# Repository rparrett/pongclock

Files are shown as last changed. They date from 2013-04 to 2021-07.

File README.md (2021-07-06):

Pongclock
=========

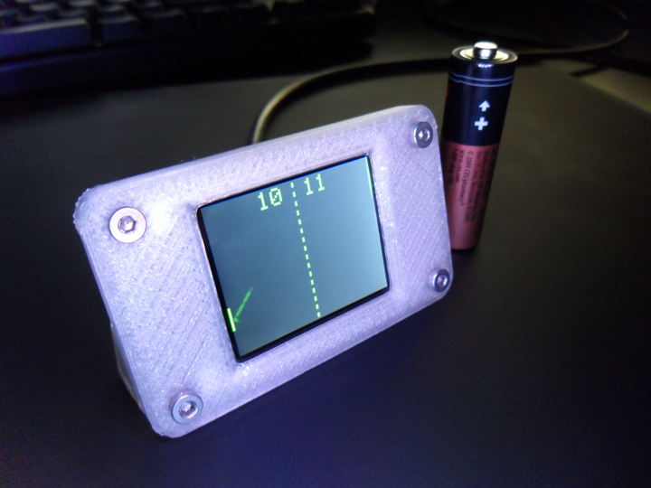
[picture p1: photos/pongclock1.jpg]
Pongclock


* it's a clock
* arduino compatible
* 1.8" tft display
* powered by usb
* 4 buttons

Dependencies
============
* Arduino 1.6.9
* https://github.com/adafruit/Adafruit-ST7735-Library @ 8ad728d736d32820dab30c9653d1a61fb6a33ab8
* https://github.com/adafruit/Adafruit-GFX-Library @ 334e815bc1dd3f93f93c45b77b4f33bdc9bfc8c5
* https://github.com/adafruit/RTClib @ f0385ab04897f27e7f625eb7a8d2c7671051df96
* https://github.com/thomasfredericks/Bounce2 @ 8b60f9f057db7dbf7dfd395cfcc2ecaadb4ccb9a

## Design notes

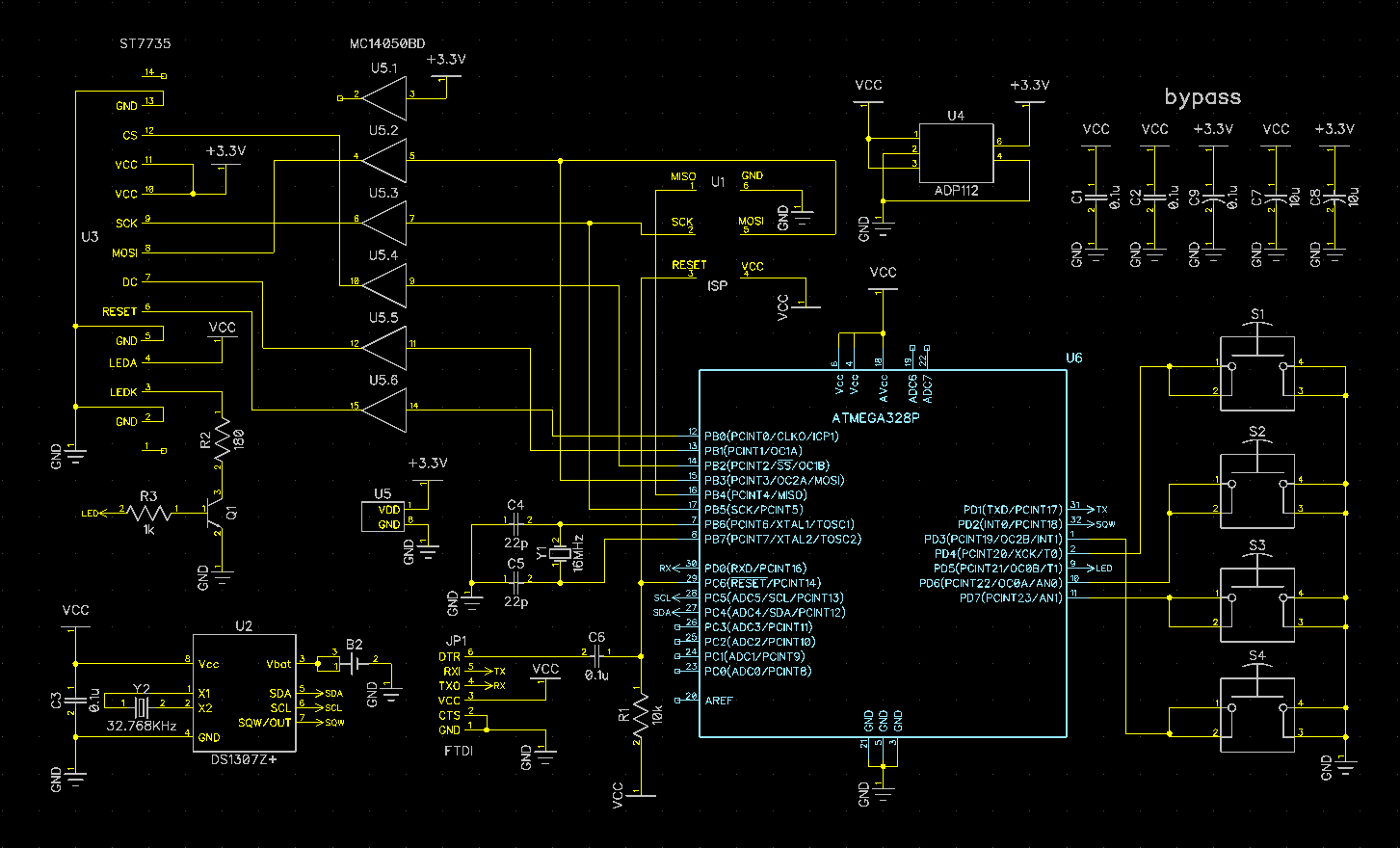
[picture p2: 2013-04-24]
schematic.PNG

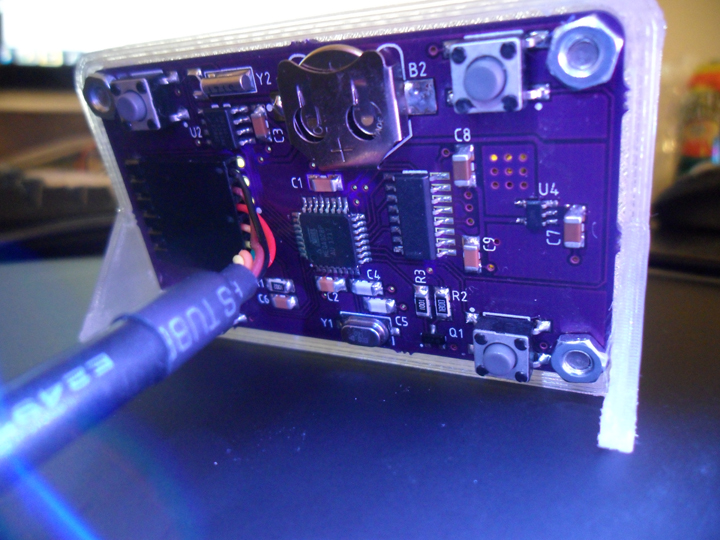
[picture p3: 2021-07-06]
photos/pongclock2.jpg

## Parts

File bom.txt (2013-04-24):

B1		3000				http://www.digikey.com/product-detail/en/3000/3000K-ND/227440
C1		0.1u				http://www.digikey.com/product-detail/en/C1206C104K5RACTU/399-1249-1-ND/411524
C2		0.1u				http://www.digikey.com/product-detail/en/C1206C104K5RACTU/399-1249-1-ND/411524	
C3		0.1u				http://www.digikey.com/product-detail/en/C1206C104K5RACTU/399-1249-1-ND/411524
C4		22p					http://www.digikey.com/product-detail/en/C1206C220K5GACTU/399-8165-1-ND/3471888
C5		22p					http://www.digikey.com/product-detail/en/C1206C220K5GACTU/399-8165-1-ND/3471888
C6		0.1u				http://www.digikey.com/product-detail/en/C1206C104K5RACTU/399-1249-1-ND/411524
C7		10u					http://www.digikey.com/product-detail/en/C1206C106Z8VACTU/399-1299-1-ND/417872
C8		10u					http://www.digikey.com/product-detail/en/C1206C106Z8VACTU/399-1299-1-ND/417872
C9		0.1u				http://www.digikey.com/product-detail/en/C1206C104K5RACTU/399-1249-1-ND/411524
JP1		FTDI				https://www.sparkfun.com/products/553
Q1		PMBT2222			http://www.digikey.com/product-detail/en/PMBT2222A,215/568-1738-1-ND/763512
R1		10k					http://www.digikey.com/product-detail/en/1623404-1/A106069CT-ND/3477720
R2		180					http://www.digikey.com/product-detail/en/RC1206FR-07180RL/311-180FRCT-ND/731544
R3		1k					http://www.digikey.com/product-detail/en/1623440-1/A106070CT-ND/3477722
S1		PTS645SH50SMTRLFS	http://www.digikey.com/product-detail/en/PTS645SH50SMTRLFS/CKN9085DKR-ND/1870056
S2		PTS645SH50SMTRLFS	http://www.digikey.com/product-detail/en/PTS645SH50SMTRLFS/CKN9085DKR-ND/1870056
S3		PTS645SH50SMTRLFS	http://www.digikey.com/product-detail/en/PTS645SH50SMTRLFS/CKN9085DKR-ND/1870056
S4		PTS645SH50SMTRLFS	http://www.digikey.com/product-detail/en/PTS645SH50SMTRLFS/CKN9085DKR-ND/1870056
U2		DS1307Z+			http://www.digikey.com/product-detail/en/DS1307Z%2BT%26R/DS1307Z%2BT%26RCT-ND/3647910
U3		ST7735				http://www.ebay.com/itm/1-8-Serial-TFT-Color-LCD-Display-Module-With-SPI-Interface-5-IO-Ports-128X160-/350676068099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
U4		TLV70033DDCT		http://www.digikey.com/product-detail/en/TLV70033DDCT/296-25276-1-ND/2176454
U5		MC14050BD			http://www.digikey.com/product-detail/en/MC14050BDR2G/MC14050BDR2GOSCT-ND/1139669
U6		ATMEGA328P			http://www.digikey.com/product-detail/en/ATMEGA328P-AUR/ATMEGA328P-AURCT-ND/3789455
Y1		16MHz				http://www.digikey.com/product-detail/en/ECS-160-20-3X-TR/XC1776CT-ND/2676640
Y2		32.768KHz			http://www.digikey.com/scripts/DkSearch/dksus.dll?vendor=0&keywords=300-8763-ND

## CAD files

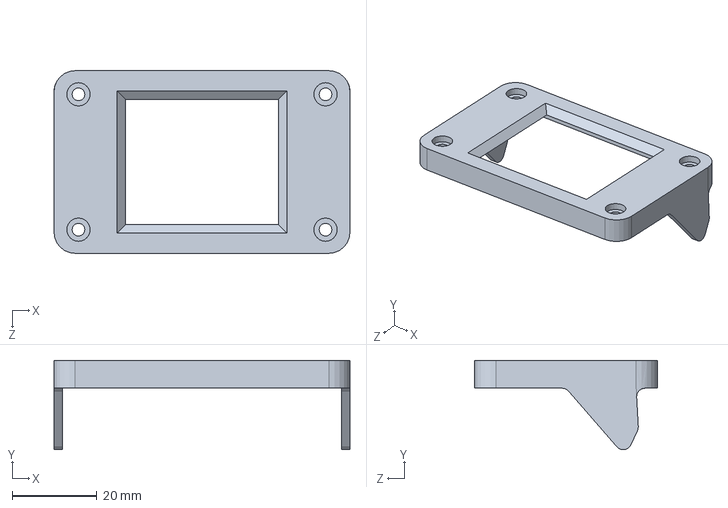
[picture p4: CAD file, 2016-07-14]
faceplate.SLDPRT
70.0 x 21.1 x 43.2 mm

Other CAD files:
faceplate.STL

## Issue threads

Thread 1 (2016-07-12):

Button S4 is for???

zoomx, 2016-07-12:
In the schematic there is a button labelled S4 that is connected to PD3 (D3 on Arduino) but it seems that in the sketch there is not any code about it.

rparrett, 2016-07-12:
You're correct. It's unused at the moment.

I intended it to be used for a two-player game mode, but never got around to it and haven't worked on the thing in years.

Closed 2016-07-14.

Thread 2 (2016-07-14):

Square Wave from DS1307 not enabled?

zoomx, 2016-07-14:
It seems that in the sketch there is no code to enable the square wave output from DS1307.

In initclock() I added these

```
  //Enable Square Wave Output
  Wire.beginTransmission(DS1307_I2C_ADDRESS);
  Wire.write(0x07); // move pointer to SQW address
  Wire.write(0x10); // sends 0x10 (hex) 00010000 (binary)
  Wire.endTransmission();
```
and a
#define DS1307_I2C_ADDRESS 0x68
at the beginning

I made a porting for cheap OLED display here
[https://github.com/zoomx/OLED-Pong-Clock](url)

rparrett, 2016-07-14:
It looks like newer versions of RTClib actually have support built-in for various square wave output settings, so I've implemented it that way.

I wonder why my DS1307 seems to default to 1hz square wave mode.

If you get a chance, I'd love to see pictures/video of pongclock running on another device!

Thanks!

Closed 2016-07-14.

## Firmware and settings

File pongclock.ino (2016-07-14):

#include <Bounce2.h> // https://github.com/thomasfredericks/Bounce2/ @ 8b60f9f057db7dbf7dfd395cfcc2ecaadb4ccb9a
#include <SPI.h>
#include <Wire.h>
#include <EEPROM.h>
#include "RTClib.h" // https://github.com/adafruit/RTClib @ f0385ab04897f27e7f625eb7a8d2c7671051df96
#include <Adafruit_GFX.h>    // https://github.com/adafruit/Adafruit-GFX-Library @ 334e815bc1dd3f93f93c45b77b4f33bdc9bfc8c5
#include <Adafruit_ST7735.h> // https://github.com/adafruit/Adafruit-ST7735-Library @ 8ad728d736d32820dab30c9653d1a61fb6a33ab8

#define PONGCLOCK "pck"

struct {
  char pongclock[4];
  byte ledpwm;
} settings = {
  PONGCLOCK,
  0
};

byte ledpwm_steps[4] = { 255, 128, 64, 16 };

#define cs   10
#define dc   9
#define rst  8

Adafruit_ST7735 tft = Adafruit_ST7735(cs, dc, rst);

int sqw = 2;
int ledbtn = 4;
int minutebtn = 6;
int hourbtn = 7;

int led = 5;

Bounce minutebouncer = Bounce(minutebtn, 20);
Bounce hourbouncer = Bounce(hourbtn, 20);
Bounce ledbouncer = Bounce(ledbtn, 20);

RTC_DS1307 RTC;

int16_t h = 128;
int16_t w = 160;

int pause = 0;

int16_t paddle_h = 20;
int16_t paddle_w = 2;

int16_t lpaddle_x = 0;
int16_t rpaddle_x = w - paddle_w;

int16_t lpaddle_y = 0;
int16_t rpaddle_y = h - paddle_h;

int16_t lpaddle_d = 1;
int16_t rpaddle_d = -1;

int16_t lpaddle_ball_t = w - w / 4;
int16_t rpaddle_ball_t = w / 4;

int16_t target_y = 0;

int16_t ball_x = 2;
int16_t ball_y = 2;
int16_t ball_dx = 1;
int16_t ball_dy = 1;
int16_t ball_w = 3;
int16_t ball_h = 3;

int16_t dashline_h = 4;
int16_t dashline_w = 2;
int16_t dashline_n = h / dashline_h;
int16_t dashline_x = w / 2 - 1;
int16_t dashline_y = dashline_h / 2;

int16_t lscore = 12;
int16_t rscore = 4;

byte newminute = 0;
byte newhour = 0;

int16_t hour = 12;
int16_t minute = 4;
volatile int16_t second = 0;

int16_t font_s  = 2;
int16_t font_w  = 5 * font_s;
int16_t font_h  = 7 * font_s;
int16_t font_sp = 2 * font_s;

uint16_t fgcolor = ST7735_GREEN;
uint16_t bgcolor = ST7735_BLACK;

void sqwint(void) {
  second = second + 1;
}

void setup(void) {
  randomSeed(analogRead(0));
   
  Wire.begin();

  initsettings();
  inittft();
  initclock();
  initgame();
  
  pinMode(minutebtn, INPUT);
  digitalWrite(minutebtn, HIGH);
  pinMode(hourbtn, INPUT);
  digitalWrite(hourbtn, HIGH);
  pinMode(ledbtn, INPUT);
  digitalWrite(ledbtn, HIGH);
}

void savesettings() {
  for (unsigned int t = 0; t < sizeof(settings); t++) {
    EEPROM.write(t, *((char*)&settings + t));
  }
}

void initsettings() {
  if (EEPROM.read(0) == PONGCLOCK[0] &&
      EEPROM.read(1) == PONGCLOCK[1] &&
      EEPROM.read(2) == PONGCLOCK[2] &&
      EEPROM.read(3) == PONGCLOCK[3]) 
  {
    for (unsigned int t = 0; t < sizeof(settings); t++) {
      *((char*)&settings + t) = EEPROM.read(t);
    }
  } else {
    savesettings();
  }
}

void inittft() {
  tft.initR(INITR_REDTAB);   

  tft.fillScreen(ST7735_BLACK);
  tft.setRotation(3);
  tft.setTextSize(font_s);
  
  analogWrite(led, ledpwm_steps[settings.ledpwm]);
}

void initclock() {
  if (! RTC.isrunning()) {
    RTC.adjust(DateTime(__DATE__, __TIME__));
  }
  
  RTC.begin();

  RTC.writeSqwPinMode(SquareWave1HZ);
  
  DateTime now = RTC.now();

  hour   = now.hour();
  minute = now.minute();
  second = now.second();
 
  if (hour > 12) hour = hour - 12;
  
  attachInterrupt(0, sqwint, FALLING);
  pinMode(sqw, INPUT);
  digitalWrite(sqw, HIGH);
}

void initgame() {
  lpaddle_y = random(0, h - paddle_h);
  rpaddle_y = random(0, h - paddle_h);

  // ball is placed on the center of the left paddle
  ball_y = lpaddle_y + (paddle_h / 2);
  
  lscore = hour;
  rscore = minute;

  calc_target_y();
}

void loop() {
  keeptime();
  
  lpaddle();
  rpaddle();
  ball();
  midline();
  score(fgcolor);
  
  buttons();
  //delay();
}

void buttons() {
  minutebouncer.update();
  if (minutebouncer.fallingEdge()) {
    minute = minute + 1;
    if (minute > 59) minute = 0;
    
    second = 0;
    
    newminute = 1;
    
    changescore(false);
    
    setclock();
  }
  
  hourbouncer.update();
  if (hourbouncer.fallingEdge()) {
    hour = hour + 1;
    if (hour > 12) hour = 1;
    
    newhour = 1;
    
    changescore(false);
    
    setclock();
  }
  
  ledbouncer.update();
  if (ledbouncer.fallingEdge()) {
    settings.ledpwm++;
    if (settings.ledpwm > sizeof(ledpwm_steps) - 1) {
      settings.ledpwm = 0;
    }
    
    analogWrite(led, ledpwm_steps[settings.ledpwm]);
    savesettings();
  }
}

void setclock() {
  DateTime now = RTC.now();
  DateTime updated = DateTime(now.year(), now.month(), now.day(), hour, minute, now.second());
  RTC.adjust(updated);
  RTC.begin();
}

void keeptime() {
  if (second > 59) {
    newminute = 1;

    second = 0;
    
    minute = minute + 1;
  }

  if (minute > 59) {
    newminute = 0;
    newhour = 1;
    
    minute = 0;
    hour = hour + 1;
  }

  if (hour > 12) {
    hour = 1;
  }
}

void midline() {
  for(int16_t i = 0; i < dashline_n; i = i + 2) {
    tft.fillRect(dashline_x, dashline_y + i * dashline_h, dashline_w, dashline_h, fgcolor);
  }

  for(int16_t i = 1; i < dashline_n; i = i + 2) {
    tft.fillRect(dashline_x, dashline_y + i * dashline_h, dashline_w, dashline_h, bgcolor);
  }
}

void score(int16_t color) {
  int lscore_x, rscore_x;

  if (lscore > 9) lscore_x = w / 2 - font_w - font_w - font_sp - 10;
  else lscore_x = w / 2 - font_w - 10;

  rscore_x = w / 2 + 10;

  tft.setTextColor(color);  

  tft.setCursor(lscore_x, dashline_y);
  tft.println(lscore);

  tft.setCursor(rscore_x, dashline_y);
  tft.println(rscore);
}

void lpaddle() {
  if (pause > 0) return;
  
  if (lpaddle_d == 1) {
    tft.fillRect(lpaddle_x, lpaddle_y, paddle_w, 1, bgcolor);
  } 
  else if (lpaddle_d == -1) {
    tft.fillRect(lpaddle_x, lpaddle_y + paddle_h - 1, paddle_w, 1, bgcolor);
  }

  lpaddle_y = lpaddle_y + lpaddle_d;

  if (ball_dx == 1) lpaddle_d = 0;
  else {
    if (lpaddle_y + paddle_h / 2 == target_y) lpaddle_d = 0;
    else if (lpaddle_y + paddle_h / 2 > target_y) lpaddle_d = -1;
    else lpaddle_d = 1;
  }

  if (lpaddle_y + paddle_h >= h && lpaddle_d == 1) lpaddle_d = 0;
  else if (lpaddle_y <= 0 && lpaddle_d == -1) lpaddle_d = 0;

  tft.fillRect(lpaddle_x, lpaddle_y, paddle_w, paddle_h, fgcolor);
}

void rpaddle() {
  if (pause > 0) return;
  
  if (rpaddle_d == 1) {
    tft.fillRect(rpaddle_x, rpaddle_y, paddle_w, 1, bgcolor);
  } 
  else if (rpaddle_d == -1) {
    tft.fillRect(rpaddle_x, rpaddle_y + paddle_h - 1, paddle_w, 1, bgcolor);
  }

  rpaddle_y = rpaddle_y + rpaddle_d;

  if (ball_dx == -1) rpaddle_d = 0;
  else {
    if (rpaddle_y + paddle_h / 2 == target_y) rpaddle_d = 0;
    else if (rpaddle_y + paddle_h / 2 > target_y) rpaddle_d = -1;
    else rpaddle_d = 1;
  }

  if (rpaddle_y + paddle_h >= h && rpaddle_d == 1) rpaddle_d = 0;
  else if (rpaddle_y <= 0 && rpaddle_d == -1) rpaddle_d = 0;

  tft.fillRect(rpaddle_x, rpaddle_y, paddle_w, paddle_h, fgcolor);
}

void calc_target_y() {
  int16_t target_x;
  int16_t reflections;
  int16_t y;

  if (ball_dx == 1) {
    target_x = w - ball_w;
  } 
  else {
    target_x = -1 * (w - ball_w);
  }

  y = abs(target_x * (ball_dy / ball_dx) + ball_y);

  reflections = floor(y / h);

  if (reflections % 2 == 0) {
    target_y = y % h;
  } 
  else {
    target_y = h - (y % h);
  }
  
  // when the time changes, we want to dodge the ball
  // instead of seeking it.
  
  if (newminute && ball_dx == -1) {
    if (target_y > h - paddle_h) {
      target_y = target_y - paddle_h;
    } else {
      target_y = target_y + paddle_h;
    }
  } else if (newhour && ball_dx == 1) {
    if (target_y > h - paddle_h) {
      target_y = target_y - paddle_h;
    } else {
      target_y = target_y + paddle_h;
    }
  }
}

void changescore(int newgame) {
  score(bgcolor);
  
  if (newhour) {
    lscore = hour;
    rscore = minute;
    newhour = 0;
    newminute = 0;
  } else if (newminute) {
    rscore = minute;
    newminute = 0;
  }
  
  if (newgame) {
    pause = 200;
    
    ball_x = paddle_w;
    ball_y = lpaddle_y + (paddle_h / 2);
    ball_dx = 1;

    calc_target_y();
  }
}

void ball() {
  if (pause > 0) { pause = pause - 1; return; } 
  
  tft.fillRect(ball_x, ball_y, ball_w, ball_h, bgcolor);

  ball_x = ball_x + ball_dx;
  ball_y = ball_y + ball_dy;

  if (ball_dx == -1 && ball_x == paddle_w && ball_y + ball_h >= lpaddle_y && ball_y <= lpaddle_y + paddle_h) {
    ball_dx = ball_dx * -1;
    
    calc_target_y(); 
  } else if (ball_dx == 1 && ball_x + ball_w == w - paddle_w && ball_y + ball_h >= rpaddle_y && ball_y <= rpaddle_y + paddle_h) {
    ball_dx = ball_dx * -1;
    
    calc_target_y();
  } else if ((ball_dx == 1 && ball_x >= w) || (ball_dx == -1 && ball_x + ball_w < 0)) {
    changescore(1);
  }

  if (ball_y > h - ball_w || ball_y < 0) {
    ball_dy = ball_dy * -1;
  }

  tft.fillRect(ball_x, ball_y, ball_w, ball_h, fgcolor);
}

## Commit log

2013-10-31 Fix bug where paddle would dodge in wrong direction sometimes. (Thanks KaR]V[aN)
    [pongclock.ino]
2013-10-31 Fix bug where left paddle could lose when minutes roll over. (Thanks KaR]V[aN)
    [pongclock.ino]
2014-06-28 Updated faceplate with (hopefully) more correct measurements and counter-sunk bolt holes.
    [faceplate.SLDPRT, faceplate.STL]
2016-07-14 Fix narrowing conversion warning.
    [pongclock.ino]
2016-07-14 Updated faceplate geometry
    [faceplate.SLDPRT, faceplate.STL]
